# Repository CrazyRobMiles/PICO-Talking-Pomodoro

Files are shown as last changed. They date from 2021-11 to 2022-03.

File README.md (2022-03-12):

# PICO Talking Pomodoro

Designs and software for a PICO Talking Pomodoro presented in Hackspace magazine.

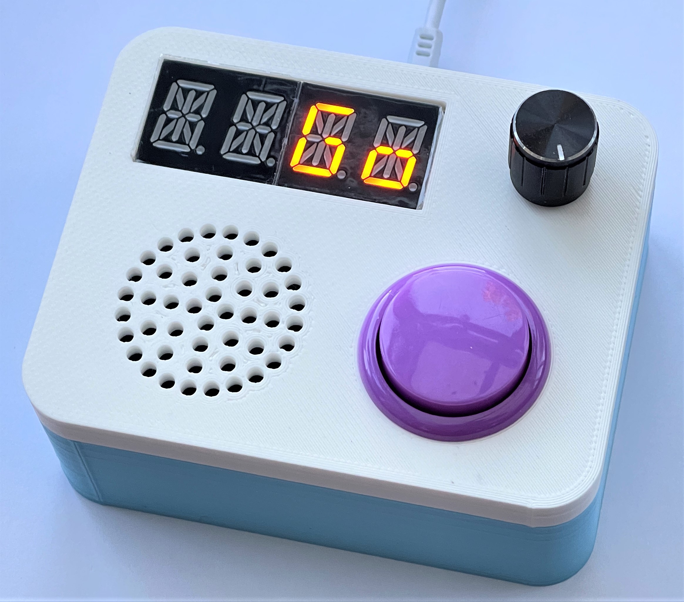
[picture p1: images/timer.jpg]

## Video
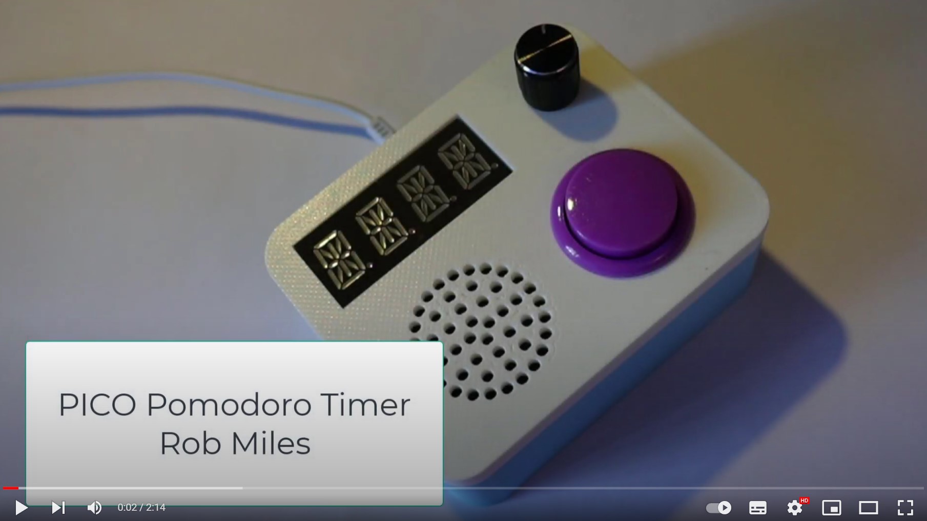
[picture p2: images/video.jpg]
YouTube Screenshot (https://youtu.be/dRORE6ujpsI)


To find out more about the device click on the image above to see a short video.

## Using the Pomodoro
There are two controls on the Pomodoro. A knob (rotary encoder) you can turn to select settings and a big button you can press. You can also use the knob as a button by pressing it in. 

When you power up the device it says Hi and then displays "Set". Set the time by turning the knob to select the number of hours and minutes that you want the timer to run for. When you have selected the time, push in the knob or press the button. The screen will now display "Up". 

If you want the timer to count elapsed time push in the knob or press the button. If you want the timer to count down (and tell you how much time is left) turn the knob until "Down" is displayed. When you have selected the required direction, push in the knob or press the button. 

Now you select the feedback that you want. You can rotate the knob to select between "None", "Disp", "Five", "Ten" and "Rand":

* None - the time will not be displayed. The timer will play a chime when the time completes
* Disp - the time will be displayed but the timer will be silent.
* Five - the time will be displayed and the timer will announce the time every five minutes. 
* Ten - the time will be displayed and the timer will announce the time every Ten minutes. 
* Rand - - the time will be displayed and the timer will announce the time at random intervals.

When you have selected the feedback that you want, push in the knob or press the button. The timer will display GO, which means that it is ready to run. Now press the button or push in the knob to start the clock ticking. If you have selected a display you will see it on the screen. You will also hear time announcements if you have selected them. 
To check the time at any other point, press the button and the time will be announced and displayed, depending on what you have selected. 

To stop the timer early press in on the rotary control and select "Stop" from the menu that appears. If you select "Cont" the timer will continue.

## Hardware
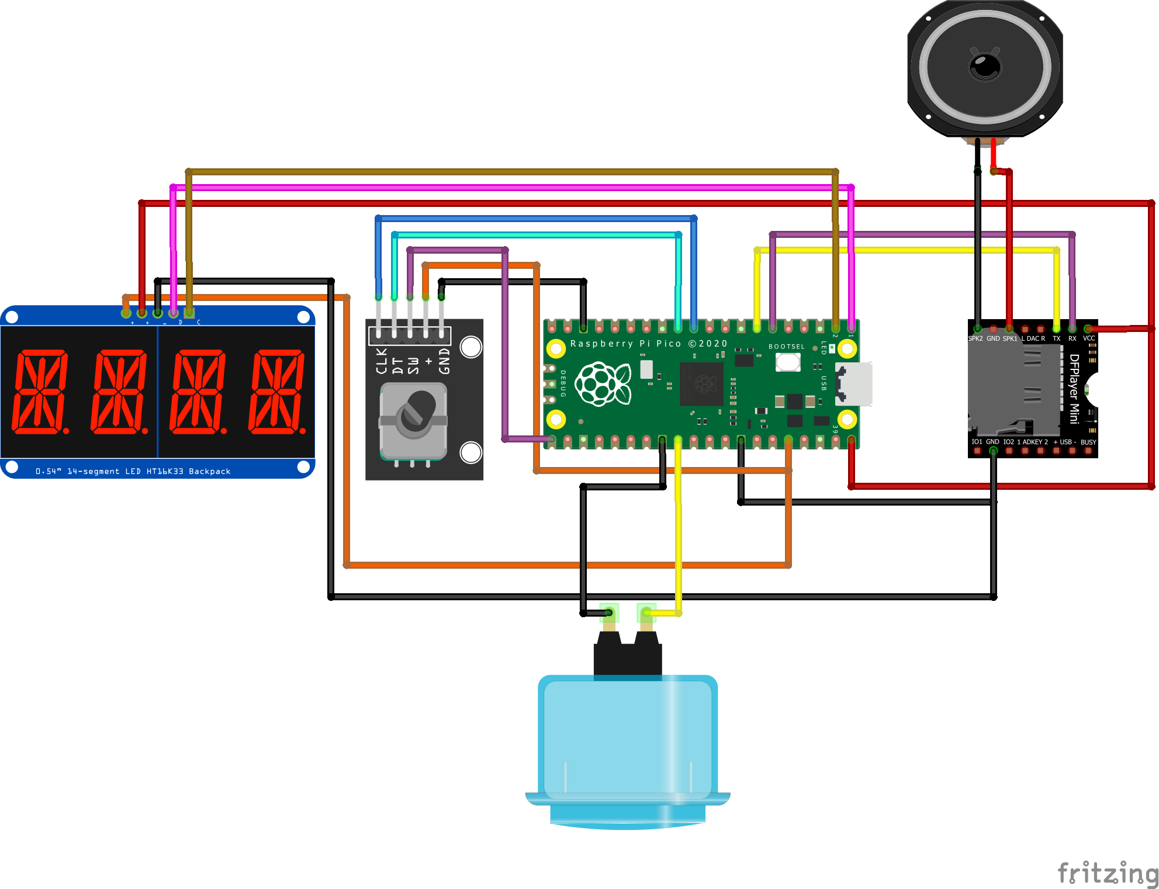
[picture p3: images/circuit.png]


You will need the following hardware items:

* A Raspberry Pi PICO
* A DFPlayer Mini MP3 player (search for "DFPlayer Mini") 
* A MicroSD card. This is perhaps the most expensive component. However, you don't need a very large one. The author used an 8 Gigabyte card that he received with a tiny camera many years ago.
* A four character alphanumeric display with an HT16K33 backpack. Search for "ht16k33 14 segment led". Make sure that you get the 14 segment device as this can display text.
* A large push button (preferably one with a nice colour)
* A rotary encoder (search for KY-040 encoder)
* A small speaker (You can get a very nice one from Pimoroni: https://shop.pimoroni.com/products/mini-speaker-4-3w)
* A micro-USB cable to link the PICO to the host
* Connecting wire (search for "30 AWG wire wrap") which needs a wire wrap tool (search for "wire wrap tool").
* A box. There is a 3D printable design, or you can put your timer in any box you fancy.
* Screws. You'll need some screws sized M2 4mm in length to fix things to the case (search for "laptop screws")
* Sticky fixer. The MP3 player does not have any fixing holes, so you must stick it inside the case using double sided tape or a “sticky fixer” pad.

## Sound files

The Sounds folder contains the MP3 samples used for the announcements. These must be copied onto a MicroSD card which is inserted into the DFPlayer. Note that they must be copied in order as the player ignores filenames and just uses the file position in the folder directory. If you copy all the files at once they may not be copied in the correct oder. The program FileCopier.py in the sounds folder can be used to copy the files one at a time into a card. 

## Program files

You can find the Circuit Python program in the code folder. Store this as code.py on your device so that it runs when it is powered up. Make sure you are using Version 7 of Circuit Python. 

## Case designs

There are 3D printable designs for the case in the case folder. The two parts are a friction fit.

## Lib

The timer uses a collection of Circuit Python library files that must be stored in the lib folder on your device. The lib folder contains all the requried files. Copy the contents into the lib folder on your device.

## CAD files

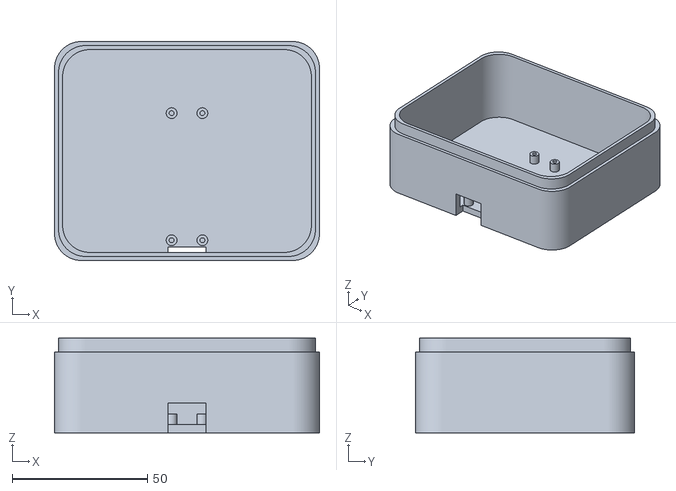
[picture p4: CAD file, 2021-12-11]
case/base.stl
98.0 x 81.0 x 35.0

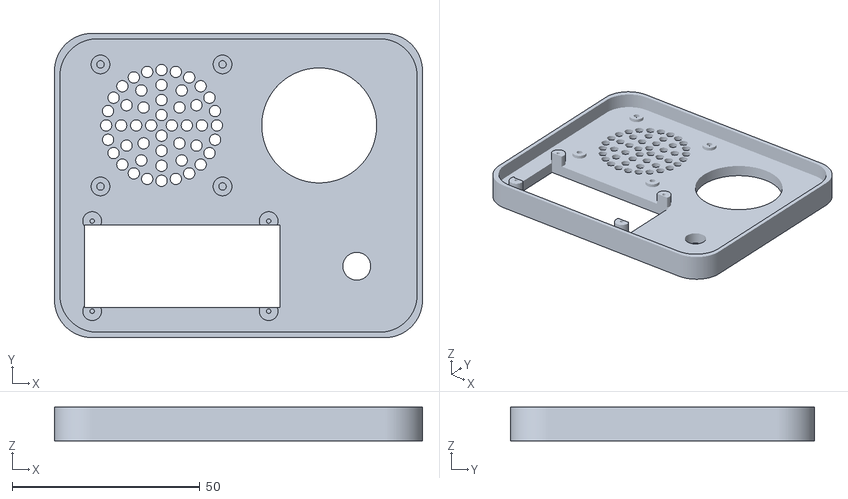
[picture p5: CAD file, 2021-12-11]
case/top.stl
98.0 x 81.0 x 9.00

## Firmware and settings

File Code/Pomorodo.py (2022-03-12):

import board
import busio
import time
import random
import rotaryio
from digitalio import DigitalInOut, Direction, Pull
from adafruit_debouncer import Debouncer
from DFPlayer import DFPlayer
from adafruit_ht16k33 import segments

Version = "V2.0"

class PomodoroTimer():
    
    TIMER_STARTING = 71
    TIMER_TIME_OVER = 72
    TIMER_HOURS_AND = (60,61,62,63,64,65,66)
    TIMER_HOURS = (73,74,75,76,77,78,79)
    TIMER_GONE = 70
    TIMER_TIME_LEFT = 69
    TIMER_DING = 68
    TIMER_ZERO_MINS = 80
    
    def blocking_sound_play(self,track_no):
        self.dfplayer.play(track=track_no)
        while self.dfplayer.get_status() == 513:
            pass
    
    def __init__(self, i2c_sda,i2c_scl,
                 play_tx,play_rx,vol,
                 encoder_a,encoder_b,encoder_button,
                 time_button
                 ):
        # Make i2c connection
        self.i2c = busio.I2C(i2c_scl, i2c_sda)
        # Make display
        self.display = segments.Seg14x4(self.i2c)
        self.display_text('Hi  ')
        # Make mp3 player
        self.uart = busio.UART(tx=play_tx, rx=play_rx)
        self.dfplayer = DFPlayer(uart=self.uart,volume=vol)
        # Make encoder
        self.encoder= rotaryio.IncrementalEncoder(encoder_a, encoder_b)
        # Make encoder button
        tmp_pin = DigitalInOut(encoder_button)
        tmp_pin.pull = Pull.UP
        self.encoder_button = Debouncer(tmp_pin,interval=0.01)
        # Make time button
        tmp_pin = DigitalInOut(time_button)
        tmp_pin.pull = Pull.UP
        self.time_button = Debouncer(tmp_pin,interval=0.01)
    
    def test(self):
        print("Pomodoro Self Test",Version)
        # record the current encoder position
        old_enc_pos=self.encoder.position
        # say hello
        self.display.print("Test")
        # loop forever
        while True:
            # update the button on the encoder
            self.encoder_button.update()
            # has the encoder button been pressed?
            if self.encoder_button.fell:
                # print a message if the button was pressed
                print("Encoder pressed")
            # update the time button
            self.time_button.update()
            # has the time button been pressed
            if self.time_button.fell:
                # print a message
                print("Time pressed")
                # play some messages
                self.blocking_sound_play(67)
                self.blocking_sound_play(61)
                self.blocking_sound_play(25)
            # get the encoder position
            enc_pos=self.encoder.position
            # has the encoder been turned?
            if enc_pos != old_enc_pos:
                # display the encoder position
                self.display.fill(0)
                self.display.print(enc_pos)
                # record the old encoder position
                old_enc_pos = enc_pos
    
    def display_text(self, text):
        self.display.fill(0)
        self.display.print(text)
        
    def scroll_text(self,text):
        self.display.marquee(text, delay=0.25, loop=False)
        
    def pick_option(self,options):
        option=0
        self.display.fill(0)
        self.display.print(options[0])
        old_enc_pos=self.encoder.position
        while True:
            enc_pos=self.encoder.position
            if enc_pos != old_enc_pos:
                diff= enc_pos-old_enc_pos
                option = option + diff
                if option<0:
                    option=len(options)-1
                if option>=len(options):
                    option=0
                self.display_text(options[option])
                old_enc_pos = enc_pos
            self.encoder_button.update()
            if self.encoder_button.fell:
                return option
            self.time_button.update()
            if self.time_button.fell:
                return option
            
    def display_time_mins(self,mins):
        h = mins // 60
        m = mins % 60
        self.display_time(m,h)
        
    def display_time(self,m,h):
        s=f'{h:02d}{m:02d}'
        self.display_text(s)

    def read_time(self,max_hours=7):
        mins=0
        hours=0
        old_enc_pos=self.encoder.position
        while True:
            enc_pos=self.encoder.position
            if enc_pos != old_enc_pos:
                diff= enc_pos-old_enc_pos
                mins = mins + diff
                if mins<0:
                    if hours>0:
                        hours = hours-1
                        mins=mins+60
                    else:
                        mins=0
                if mins>59:
                    if hours<max_hours:
                        hours=hours+1
                        mins=mins-60
                    else:
                        mins=59
                old_enc_pos = enc_pos
                self.display_time(mins,hours)
            self.encoder_button.update()
            if self.encoder_button.fell:
                if mins != 0 or  hours != 0:
                    break
            self.time_button.update()
            # has the time button been pressed
            if self.time_button.fell:
                if mins != 0 or  hours != 0:
                    # if a time has been set - select it
                    break
                else:
                    # display help
                    self.scroll_text('Turn the knob to set the delay time')
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

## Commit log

2021-11-23 Fixed typos and added python code
    [Pomorodo.py]
2021-12-11 Added case designs and circuit
